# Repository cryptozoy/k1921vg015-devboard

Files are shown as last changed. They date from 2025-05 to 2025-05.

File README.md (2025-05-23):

# К1921ВГ015 DEVBOARD

Проект печатной платы для микроконтроллера К1921ВГ015 разработанный в KiCad 9.

Пожалуйста учитывайте, что фото может незначительно отличаться от платы в проекте, поскольку туда могут вноситься мелкие исправления.

Если вы хотите последнюю версию гербер файлов - рекомендуется формировать их самим, что гарантирует их актуальность.

Файлы сверловки экспортированы с настройками по умолчанию и лежат в `/gerber/`

Требования для 5$ в nextPCB были учтены и лично мной проверены.

Огромное спасибо: [@cryptozoy](https://github.com/cryptozoy) за доработку платы.

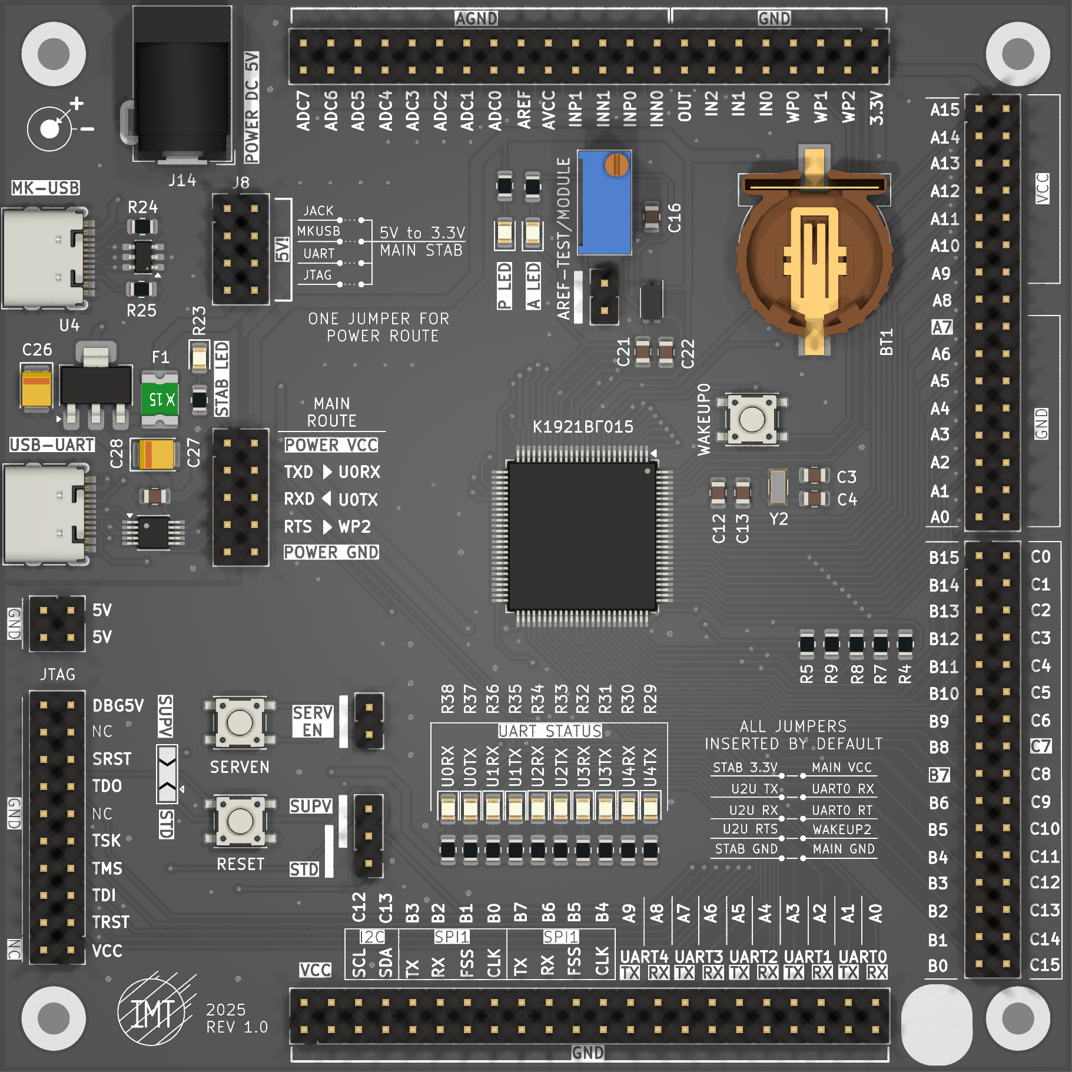
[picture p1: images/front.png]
Banner


Все пины контроллера задействованы, все функциональные пины выведены на гребёнки:

 - Порты ABC

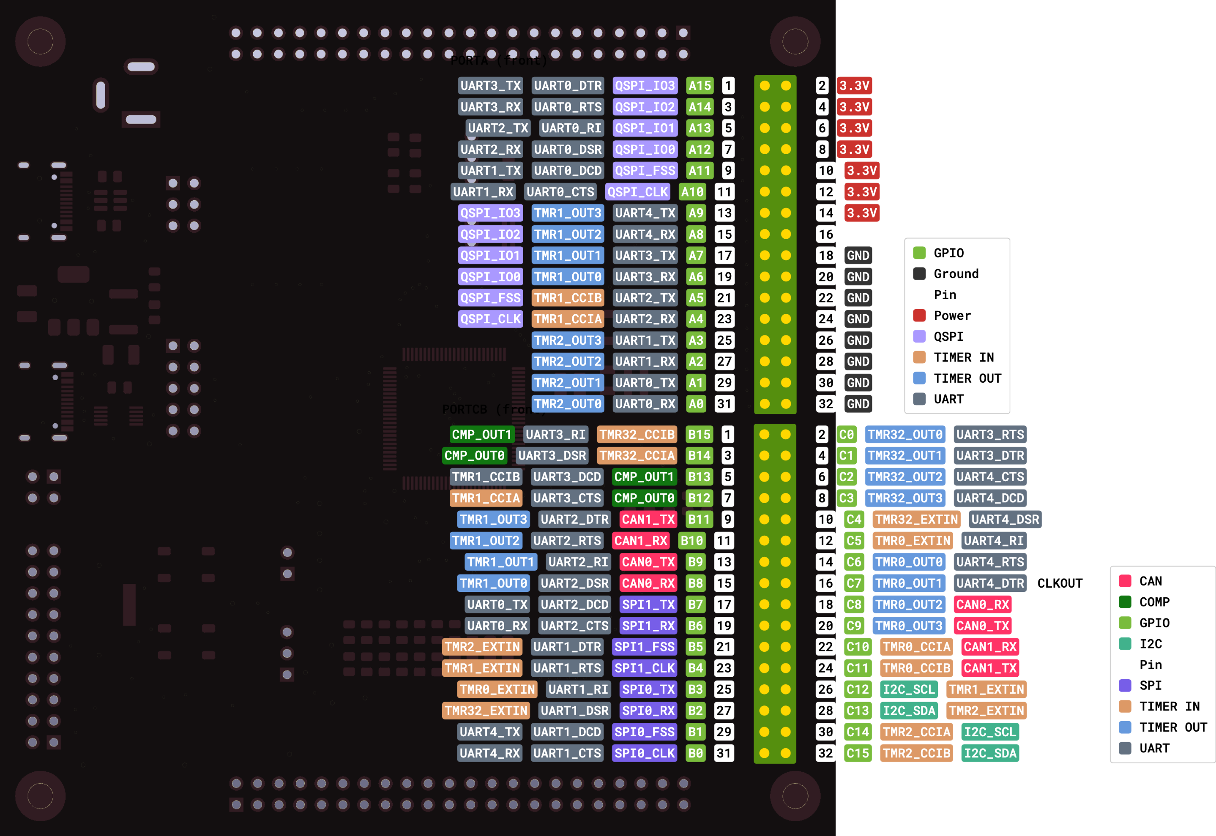
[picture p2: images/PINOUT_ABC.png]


 - Функциональные пины и коммуникация

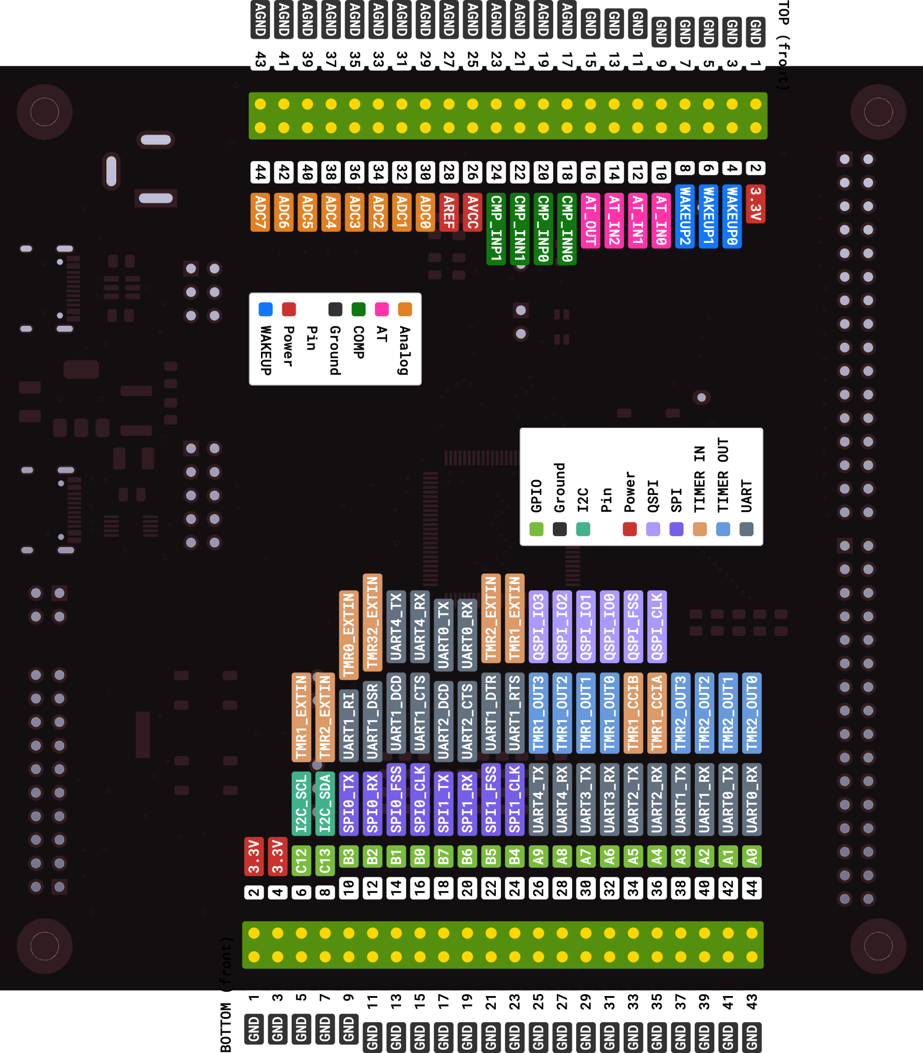
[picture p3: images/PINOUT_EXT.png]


Файлы для генерации пинаутов лежат в папке `pinouts`

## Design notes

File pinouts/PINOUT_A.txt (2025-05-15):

title: "PORTA"

# dimensions counted in pins
width: 2
height: 16

pins:
  left:
    - [ "1", "A15:gpio", "QSPI_IO3:qspi", "UART0_DTR:uart", "UART3_TX:uart"]
    - [ "3", "A14:gpio", "QSPI_IO2:qspi", "UART0_RTS:uart", "UART3_RX:uart" ]
    - [ "5", "A13:gpio", "QSPI_IO1:qspi", "UART0_RI:uart", "UART2_TX:uart" ]
    - [ "7", "A12:gpio", "QSPI_IO0:qspi", "UART0_DSR:uart", "UART2_RX:uart" ]
    - [ "9", "A11:gpio", "QSPI_FSS:qspi", "UART0_DCD:uart", "UART1_TX:uart" ]
    - [ "11", "A10:gpio", "QSPI_CLK:qspi", "UART0_CTS:uart", "UART1_RX:uart"  ]
    - [ "13", "A9:gpio", "UART4_TX:uart", "TMR1_OUT3:timo", "QSPI_IO3:qspi" ]
    - [ "15", "A8:gpio", "UART4_RX:uart", "TMR1_OUT2:timo", "QSPI_IO2:qspi" ]
    - [ "17", "A7:gpio", "UART3_TX:uart", "TMR1_OUT1:timo", "QSPI_IO1:qspi"]
    - [ "19", "A6:gpio", "UART3_RX:uart", "TMR1_OUT0:timo", "QSPI_IO0:qspi" ]
    - [ "21", "A5:gpio", "UART2_TX:uart", "TMR1_CCIB:timi", "QSPI_FSS:qspi" ]
    - [ "23", "A4:gpio", "UART2_RX:uart", "TMR1_CCIA:timi", "QSPI_CLK:qspi" ]
    - [ "25", "A3:gpio", "UART1_TX:uart", "TMR2_OUT3:timo" ]
    - [ "27", "A2:gpio", "UART1_RX:uart", "TMR2_OUT2:timo" ]
    - [ "29", "A1:gpio", "UART0_TX:uart", "TMR2_OUT1:timo" ]
    - [ "31", "A0:gpio", "UART0_RX:uart", "TMR2_OUT0:timo" ]

  right:
    - [ "2", "3.3V:power" ]
    - [ "4", "3.3V:power" ]
    - [ "6", "3.3V:power" ]
    - [ "8", "3.3V:power" ]
    - [ "10", "3.3V:power" ]
    - [ "12", "3.3V:power" ]
    - [ "14", "3.3V:power" ]
    - [ "16" ]
    - [ "18", "GND:gnd" ]
    - [ "20", "GND:gnd" ]
    - [ "22", "GND:gnd" ]
    - [ "24", "GND:gnd" ]
    - [ "26", "GND:gnd" ]
    - [ "28", "GND:gnd" ]
    - [ "30", "GND:gnd" ]
    - [ "32", "GND:gnd" ]

types:
  timo:
    bgcolor: "#6699DD"
    label: "TIMER OUT"
    fgcolor: "#FFFFFF"
  
  timi:
    bgcolor: "#DD9966"
    label: "TIMER IN"
    fgcolor: "#FFFFFF"
  
  qspi: 
    bgcolor: "#AA99FF"
    label: "QSPI"
    fgcolor: "#FFFFFF"

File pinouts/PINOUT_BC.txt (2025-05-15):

title: "PORTA"

# dimensions counted in pins
width: 2
height: 16

pins:
  left:
    - [ "1", "B15:gpio", "TMR32_CCIB:timi", "UART3_RI:uart", "CMP_OUT1:comp"]
    - [ "3", "B14:gpio", "TMR32_CCIA:timi", "UART3_DSR:uart", "CMP_OUT0:comp" ]
    - [ "5", "B13:gpio", "CMP_OUT1:comp", "UART3_DCD:uart", "TMR1_CCIB:uart" ]
    - [ "7", "B12:gpio", "CMP_OUT0:comp", "UART3_CTS:uart", "TMR1_CCIA:timi" ]
    - [ "9", "B11:gpio", "CAN1_TX:can", "UART2_DTR:uart", "TMR1_OUT3:timo" ]
    - [ "11", "B10:gpio", "CAN1_RX:can", "UART2_RTS:uart", "TMR1_OUT2:timo"  ]
    - [ "13", "B9:gpio", "CAN0_TX:can", "UART2_RI:uart", "TMR1_OUT1:timo" ]
    - [ "15", "B8:gpio", "CAN0_RX:can", "UART2_DSR:uart", "TMR1_OUT0:timo" ]
    - [ "17", "B7:gpio", "SPI1_TX:spi", "UART2_DCD:uart", "UART0_TX:uart"]
    - [ "19", "B6:gpio", "SPI1_RX:spi", "UART2_CTS:uart", "UART0_RX:uart" ]
    - [ "21", "B5:gpio", "SPI1_FSS:spi", "UART1_DTR:uart", "TMR2_EXTIN:timi" ]
    - [ "23", "B4:gpio", "SPI1_CLK:spi", "UART1_RTS:uart","TMR1_EXTIN:timi" ]
    - [ "25", "B3:gpio", "SPI0_TX:spi","UART1_RI:uart", "TMR0_EXTIN:timi" ]
    - [ "27", "B2:gpio", "SPI0_RX:spi", "UART1_DSR:uart", "TMR32_EXTIN:timi" ]
    - [ "29", "B1:gpio", "SPI0_FSS:spi", "UART1_DCD:uart", "UART4_TX:uart" ]
    - [ "31", "B0:gpio", "SPI0_CLK:spi", "UART1_CTS:uart", "UART4_RX:uart" ]

  right:
    - [ "2", "C0:gpio", "TMR32_OUT0:timo", "UART3_RTS:uart"]
    - [ "4", "C1:gpio", "TMR32_OUT1:timo", "UART3_DTR:uart" ]
    - [ "6", "C2:gpio", "TMR32_OUT2:timo", "UART4_CTS:uart" ]
    - [ "8", "C3:gpio", "TMR32_OUT3:timo", "UART4_DCD:uart" ]
    - [ "10", "C4:gpio", "TMR32_EXTIN:timi", "UART4_DSR:uart"]
    - [ "12", "C5:gpio", "TMR0_EXTIN:timi", "UART4_RI:uart"]
    - [ "14", "C6:gpio", "TMR0_OUT0:timo", "UART4_RTS:uart" ]
    - [ "16", "C7:gpio", "TMR0_OUT1:timo", "UART4_DTR:uart", "CLKOUT"  ]
    - [ "18", "C8:gpio", "TMR0_OUT2:timo", "CAN0_RX:can" ]
    - [ "20", "C9:gpio", "TMR0_OUT3:timo", "CAN0_TX:can" ]
    - [ "22", "C10:gpio", "TMR0_CCIA:timo", "CAN1_RX:can" ]
    - [ "24", "C11:gpio", "TMR0_CCIB:timo", "CAN1_TX:can" ]
    - [ "26", "C12:gpio", "I2C_SCL:i2c", "TMR1_EXTIN:timi" ]
    - [ "28", "C13:gpio", "I2C_SDA:i2c", "TMR2_EXTIN:timi" ]
    - [ "30", "C14:gpio", "TMR2_CCIA:timi", "I2C_SCL:i2c" ]
    - [ "32", "C15:gpio", "TMR2_CCIB:timi", "I2C_SDA:i2c" ]

types:
  timo:
    bgcolor: "#6699DD"
    label: "TIMER OUT"
    fgcolor: "#FFFFFF"
  
  timi:
    bgcolor: "#DD9966"
    label: "TIMER IN"
    fgcolor: "#FFFFFF"
  
  qspi: 
    bgcolor: "#AA99FF"
    label: "QSPI"
    fgcolor: "#FFFFFF"
  can: 
    bgcolor: "#FF3366"
    label: "CAN"
    fgcolor: "#FFFFFF"
  comp: 
    bgcolor: "#117711"
    label: "COMP"
    fgcolor: "#FFFFFF"

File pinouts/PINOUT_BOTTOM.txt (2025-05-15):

title: "BOTTOM"

# dimensions counted in pins
width: 2
height: 22

pins:
  left:
    - [ "1", "GND:gnd"]
    - [ "3", "GND:gnd" ]
    - [ "5", "GND:gnd" ]
    - [ "7", "GND:gnd" ]
    - [ "9", "GND:gnd" ]
    - [ "11", "GND:gnd" ]
    - [ "13", "GND:gnd" ]
    - [ "15", "GND:gnd" ]
    - [ "17", "GND:gnd"]
    - [ "19", "GND:gnd" ]
    - [ "21", "GND:gnd" ]
    - [ "23", "GND:gnd" ]
    - [ "25", "GND:gnd" ]
    - [ "27", "GND:gnd" ]
    - [ "29", "GND:gnd" ]
    - [ "31", "GND:gnd" ]
    - [ "33", "GND:gnd" ]
    - [ "35", "GND:gnd" ]
    - [ "37", "GND:gnd" ]
    - [ "39", "GND:gnd" ]
    - [ "41", "GND:gnd" ]
    - [ "43", "GND:gnd" ]
    
  right:
    - [ "2", "3.3V:power"]
    - [ "4", "3.3V:power"]
    - [ "6", "C12:gpio", "I2C_SCL:i2c", "TMR1_EXTIN:timi"]
    - [ "8", "C13:gpio", "I2C_SDA:i2c", "TMR2_EXTIN:timi" ]
    - [ "10", "B3:gpio", "SPI0_TX:spi","UART1_RI:uart", "TMR0_EXTIN:timi"]
    - [ "12", "B2:gpio", "SPI0_RX:spi", "UART1_DSR:uart", "TMR32_EXTIN:timi"]
    - [ "14", "B1:gpio", "SPI0_FSS:spi", "UART1_DCD:uart", "UART4_TX:uart" ]
    - [ "16", "B0:gpio", "SPI0_CLK:spi", "UART1_CTS:uart", "UART4_RX:uart"  ]
    - [ "18", "B7:gpio", "SPI1_TX:spi", "UART2_DCD:uart", "UART0_TX:uart" ]
    - [ "20", "B6:gpio", "SPI1_RX:spi", "UART2_CTS:uart", "UART0_RX:uart" ]
    - [ "22", "B5:gpio", "SPI1_FSS:spi", "UART1_DTR:uart", "TMR2_EXTIN:timi" ]
    - [ "24", "B4:gpio", "SPI1_CLK:spi", "UART1_RTS:uart","TMR1_EXTIN:timi" ]
    - [ "26", "A9:gpio", "UART4_TX:uart", "TMR1_OUT3:timo", "QSPI_IO3:qspi" ]
    - [ "28", "A8:gpio", "UART4_RX:uart", "TMR1_OUT2:timo", "QSPI_IO2:qspi"  ]
    - [ "30", "A7:gpio", "UART3_TX:uart", "TMR1_OUT1:timo", "QSPI_IO1:qspi" ]
    - [ "32", "A6:gpio", "UART3_RX:uart", "TMR1_OUT0:timo", "QSPI_IO0:qspi" ]
    - [ "34", "A5:gpio", "UART2_TX:uart", "TMR1_CCIB:timi", "QSPI_FSS:qspi" ]
    - [ "36", "A4:gpio", "UART2_RX:uart", "TMR1_CCIA:timi", "QSPI_CLK:qspi" ]
    - [ "38", "A3:gpio", "UART1_TX:uart", "TMR2_OUT3:timo" ]
    - [ "40", "A2:gpio", "UART1_RX:uart", "TMR2_OUT2:timo" ]
    - [ "42", "A1:gpio", "UART0_TX:uart", "TMR2_OUT1:timo" ]
    - [ "44", "A0:gpio", "UART0_RX:uart", "TMR2_OUT0:timo" ]
    
types:
  timo:
    bgcolor: "#6699DD"
    label: "TIMER OUT"
    fgcolor: "#FFFFFF"
  
  timi:
    bgcolor: "#DD9966"
    label: "TIMER IN"
    fgcolor: "#FFFFFF"
  
  qspi: 
    bgcolor: "#AA99FF"
    label: "QSPI"
    fgcolor: "#FFFFFF"
  can: 
    bgcolor: "#FF3366"
    label: "CAN"
    fgcolor: "#FFFFFF"
  comp: 
    bgcolor: "#117711"
    label: "COMP"
    fgcolor: "#FFFFFF"

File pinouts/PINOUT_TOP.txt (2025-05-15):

title: "TOP"

# dimensions counted in pins
width: 2
height: 22

pins:
  left:
    - [ "1", "GND:gnd"]
    - [ "3", "GND:gnd" ]
    - [ "5", "GND:gnd" ]
    - [ "7", "GND:gnd" ]
    - [ "9", "GND:gnd" ]
    - [ "11", "GND:gnd" ]
    - [ "13", "GND:gnd" ]
    - [ "15", "GND:gnd" ]
    - [ "17", "AGND:gnd"]
    - [ "19", "AGND:gnd" ]
    - [ "21", "AGND:gnd" ]
    - [ "23", "AGND:gnd" ]
    - [ "25", "AGND:gnd" ]
    - [ "27", "AGND:gnd" ]
    - [ "29", "AGND:gnd" ]
    - [ "31", "AGND:gnd" ]
    - [ "33", "AGND:gnd" ]
    - [ "35", "AGND:gnd" ]
    - [ "37", "AGND:gnd" ]
    - [ "39", "AGND:gnd" ]
    - [ "41", "AGND:gnd" ]
    - [ "43", "AGND:gnd" ]
    
  right:
    - [ "2", "3.3V:power"]
    - [ "4", "WAKEUP0:wkp"]
    - [ "6", "WAKEUP1:wkp"]
    - [ "8", "WAKEUP2:wkp" ]
    - [ "10", "AT_IN0:at"]
    - [ "12", "AT_IN1:at"]
    - [ "14", "AT_IN2:at"]
    - [ "16", "AT_OUT:at"]
    - [ "18", "CMP_INN0:comp"]
    - [ "20", "CMP_INP0:comp"]
    - [ "22", "CMP_INN1:comp"]
    - [ "24", "CMP_INP1:comp"]
    - [ "26", "AVCC:power" ]
    - [ "28", "AREF:power"  ]
    - [ "30", "ADC0:analog" ]
    - [ "32", "ADC1:analog" ]
    - [ "34", "ADC2:analog" ]
    - [ "36", "ADC3:analog" ]
    - [ "38", "ADC4:analog" ]
    - [ "40", "ADC5:analog" ]
    - [ "42", "ADC6:analog" ]
    - [ "44", "ADC7:analog" ]
    
types:
  timo:
    bgcolor: "#6699DD"
    label: "TIMER OUT"
    fgcolor: "#FFFFFF"
  
  timi:
    bgcolor: "#DD9966"
    label: "TIMER IN"
    fgcolor: "#FFFFFF"
  
  qspi: 
    bgcolor: "#AA99FF"
    label: "QSPI"
    fgcolor: "#FFFFFF"
  can: 
    bgcolor: "#FF3366"
    label: "CAN"
    fgcolor: "#FFFFFF"
  comp: 
    bgcolor: "#117711"
    label: "COMP"
    fgcolor: "#FFFFFF"
  wkp: 
    bgcolor: "#1177FF"
    label: "WAKEUP"
    fgcolor: "#FFFFFF"
  at: 
    bgcolor: "#ff33AA"
    label: "AT"
    fgcolor: "#FFFFFF"

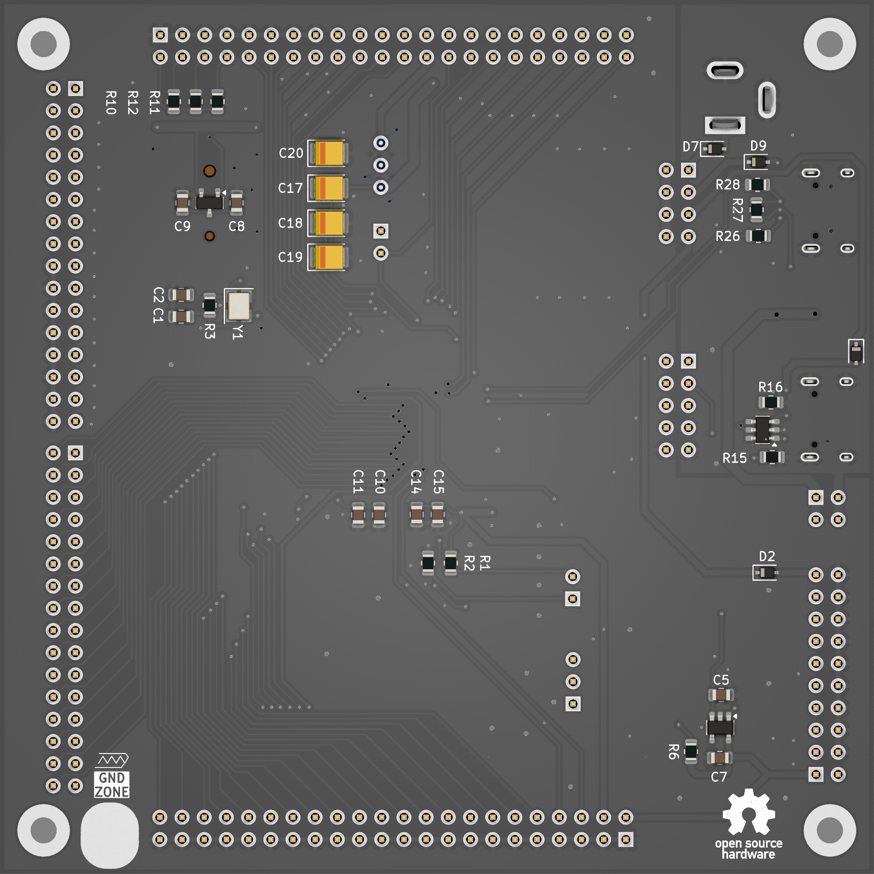
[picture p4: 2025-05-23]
images/back.png

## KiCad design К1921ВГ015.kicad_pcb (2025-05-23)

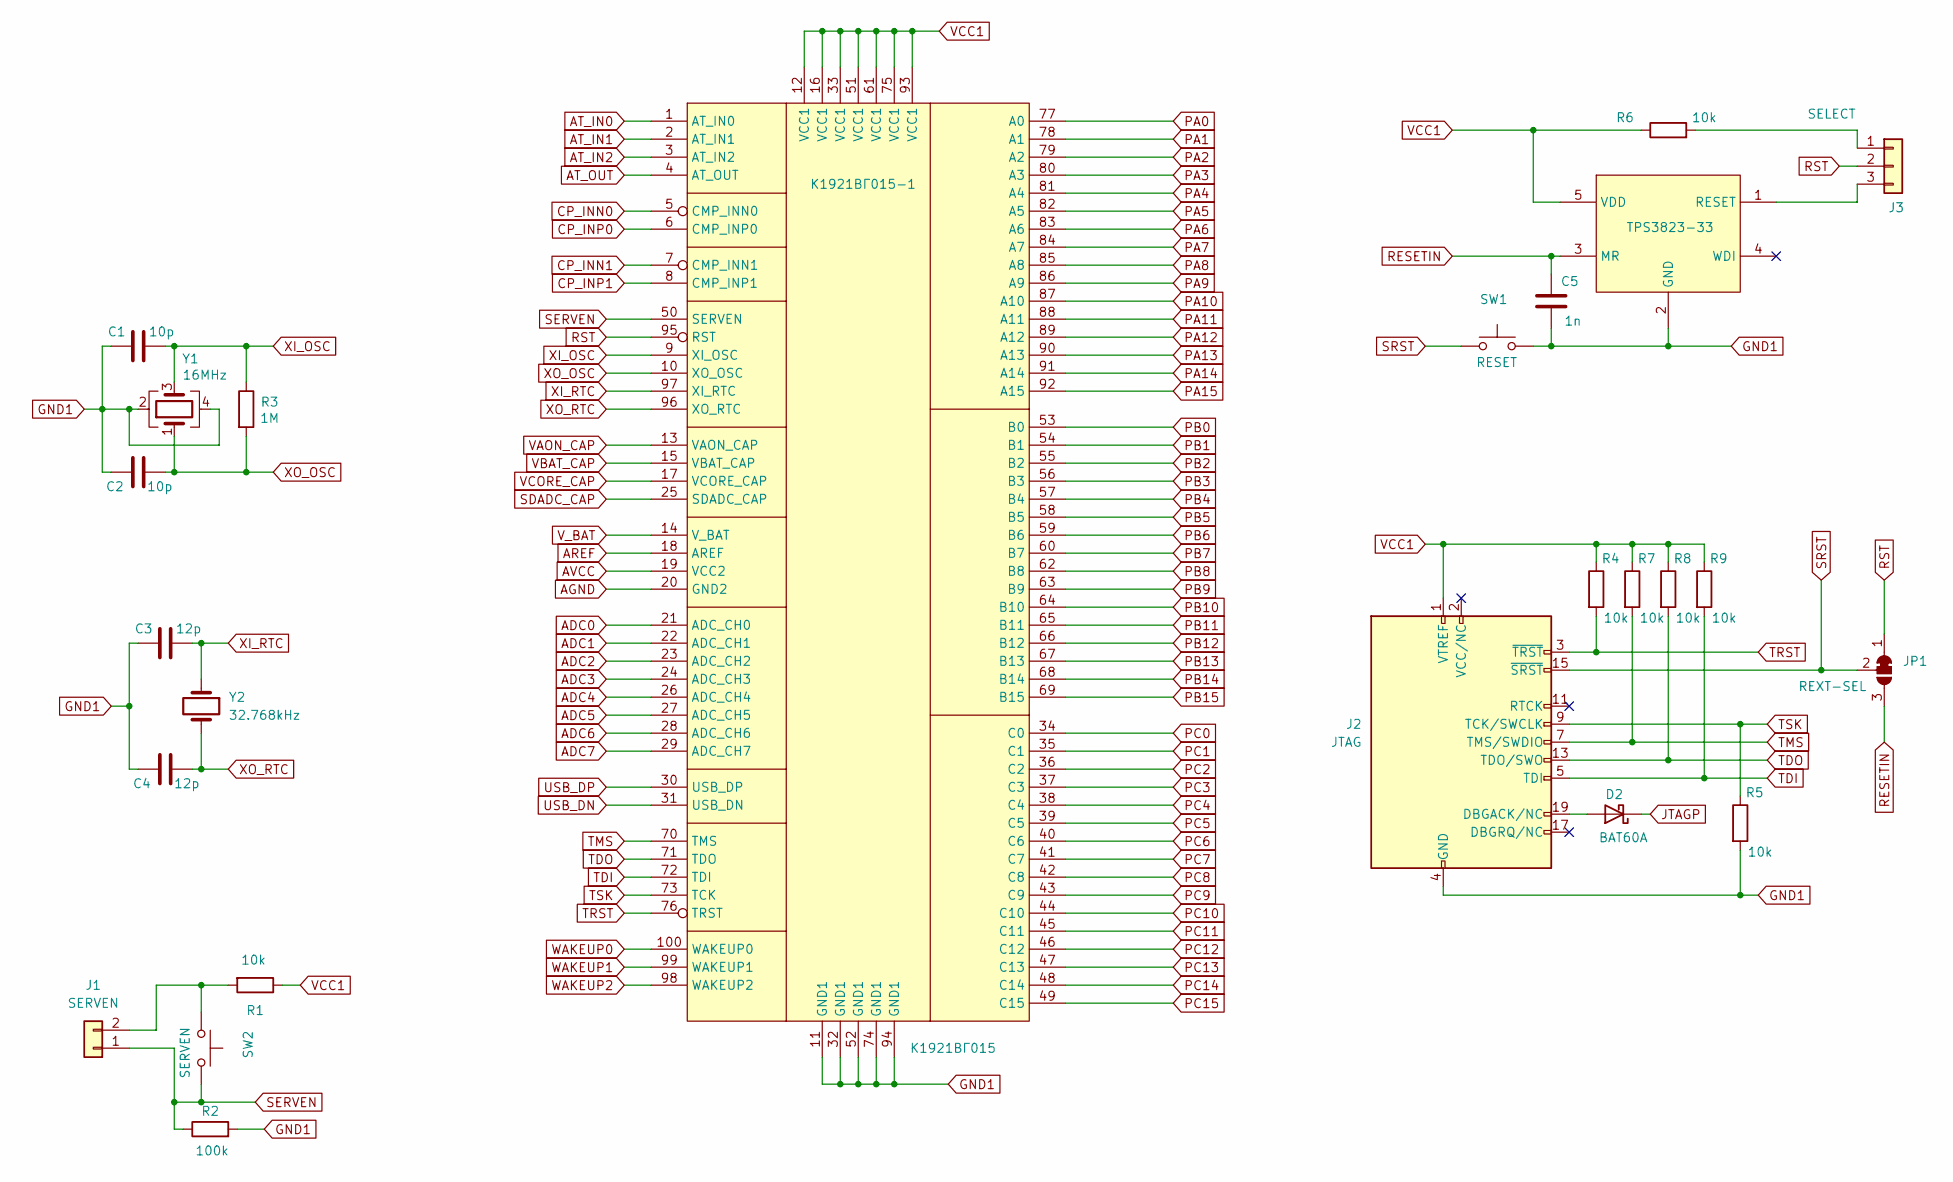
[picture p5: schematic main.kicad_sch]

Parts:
C1, C2: 10p; C_0805_2012Metric
C3, C4: 12p; C_0805_2012Metric
C5: 1n; C_0805_2012Metric
D2: BAT60A; D_SOD-323
J1: SERVEN; PinHeader_1x02_P2.54mm_Vertical
J2: JTAG; PinHeader_2x10_P2.54mm_Vertical
J3: SELECT; PinHeader_1x03_P2.54mm_Vertical
JP1: REXT-SEL; SolderJumper-3_P2.0mm_Open_TrianglePad1.0x1.5mm
R1, R4, R5, R6, R7, R8, R9: 10k; R_0805_2012Metric
R2: 100k; R_0805_2012Metric
R3: 1M; R_0805_2012Metric
SW1: RESET; SW_SPST_PTS647_Sx38
SW2: SERVEN; SW_SPST_PTS647_Sx38
TPS3823-1: TPS3823-33; SOT-23-5
Y1: 16MHz; Crystal_SMD_3225-4Pin_3.2x2.5mm
Y2: 32.768kHz; Crystal_SMD_3215-2Pin_3.2x1.5mm
К1921ВГ015-1: К1921ВГ015; LQFP-100_14x14mm_P0.5mm

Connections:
ADC0: К1921ВГ015-1.21 (ADC_CH0); also elsewhere on the board
ADC1: К1921ВГ015-1.22 (ADC_CH1); also elsewhere on the board
ADC2: К1921ВГ015-1.23 (ADC_CH2); also elsewhere on the board
ADC3: К1921ВГ015-1.24 (ADC_CH3); also elsewhere on the board
ADC4: К1921ВГ015-1.26 (ADC_CH4); also elsewhere on the board
ADC5: К1921ВГ015-1.27 (ADC_CH5); also elsewhere on the board
ADC6: К1921ВГ015-1.28 (ADC_CH6); also elsewhere on the board
ADC7: К1921ВГ015-1.29 (ADC_CH7); also elsewhere on the board
AGND: К1921ВГ015-1.20 (GND2); also elsewhere on the board
AREF: К1921ВГ015-1.18 (AREF); also elsewhere on the board
AT_IN0: К1921ВГ015-1.1 (AT_IN0); also elsewhere on the board
AT_IN1: К1921ВГ015-1.2 (AT_IN1); also elsewhere on the board
AT_IN2: К1921ВГ015-1.3 (AT_IN2); also elsewhere on the board
AT_OUT: К1921ВГ015-1.4 (AT_OUT); also elsewhere on the board
AVCC: К1921ВГ015-1.19 (VCC2); also elsewhere on the board
CAN0_RX: К1921ВГ015-1.42 (C8); also elsewhere on the board
CAN0_TX: К1921ВГ015-1.43 (C9); also elsewhere on the board
CAN1_RX: К1921ВГ015-1.44 (C10); also elsewhere on the board
CAN1_TX: К1921ВГ015-1.45 (C11); also elsewhere on the board
CP_INN0: К1921ВГ015-1.5 (CMP_INN0); also elsewhere on the board
CP_INN1: К1921ВГ015-1.7 (CMP_INN1); also elsewhere on the board
CP_INP0: К1921ВГ015-1.6 (CMP_INP0); also elsewhere on the board
CP_INP1: К1921ВГ015-1.8 (CMP_INP1); also elsewhere on the board
GND1: C1.2, C2.2, C3.2, C4.2, C5.2, J2.4 (GND), J2.6 (GND), J2.8 (GND), J2.10 (GND), J2.12 (GND), J2.14 (GND), J2.16 (GND), J2.18 (GND), J2.20 (GND), R2.2, R5.2, SW1.2, TPS3823-1.2 (GND), Y1.2, Y1.4, К1921ВГ015-1.11 (GND1), К1921ВГ015-1.32 (GND1), К1921ВГ015-1.52 (GND1), К1921ВГ015-1.74 (GND1), К1921ВГ015-1.94 (GND1); also elsewhere on the board
I2C_SCL: К1921ВГ015-1.46 (C12); also elsewhere on the board
I2C_SDA: К1921ВГ015-1.47 (C13); also elsewhere on the board
unnamed: D2.2 (A), J2.19 (DBGACK/NC)
unnamed: J1.2, R1.2, SW2.1
unnamed: J3.1, R6.2
unnamed: J3.3, TPS3823-1.1 (RESET)
PA0: К1921ВГ015-1.77 (A0); also elsewhere on the board
PA1: К1921ВГ015-1.78 (A1); also elsewhere on the board
PA2: К1921ВГ015-1.79 (A2); also elsewhere on the board
PA3: К1921ВГ015-1.80 (A3); also elsewhere on the board
PA4: К1921ВГ015-1.81 (A4); also elsewhere on the board
PA5: К1921ВГ015-1.82 (A5); also elsewhere on the board
PA6: К1921ВГ015-1.83 (A6); also elsewhere on the board
PA7: К1921ВГ015-1.84 (A7); also elsewhere on the board
PA8: К1921ВГ015-1.85 (A8); also elsewhere on the board
PA9: К1921ВГ015-1.86 (A9); also elsewhere on the board
PA10: К1921ВГ015-1.87 (A10); also elsewhere on the board
PA11: К1921ВГ015-1.88 (A11); also elsewhere on the board
PA12: К1921ВГ015-1.89 (A12); also elsewhere on the board
PA13: К1921ВГ015-1.90 (A13); also elsewhere on the board
PA14: К1921ВГ015-1.91 (A14); also elsewhere on the board
PA15: К1921ВГ015-1.92 (A15); also elsewhere on the board
PB0: К1921ВГ015-1.53 (B0); also elsewhere on the board
PB1: К1921ВГ015-1.54 (B1); also elsewhere on the board
PB2: К1921ВГ015-1.55 (B2); also elsewhere on the board
PB3: К1921ВГ015-1.56 (B3); also elsewhere on the board
PB4: К1921ВГ015-1.57 (B4); also elsewhere on the board
PB5: К1921ВГ015-1.58 (B5); also elsewhere on the board
PB6: К1921ВГ015-1.59 (B6); also elsewhere on the board
PB7: К1921ВГ015-1.60 (B7); also elsewhere on the board
PB8: К1921ВГ015-1.62 (B8); also elsewhere on the board
PB9: К1921ВГ015-1.63 (B9); also elsewhere on the board
PB10: К1921ВГ015-1.64 (B10); also elsewhere on the board
PB11: К1921ВГ015-1.65 (B11); also elsewhere on the board
PB12: К1921ВГ015-1.66 (B12); also elsewhere on the board
PB13: К1921ВГ015-1.67 (B13); also elsewhere on the board
PB14: К1921ВГ015-1.68 (B14); also elsewhere on the board
PB15: К1921ВГ015-1.69 (B15); also elsewhere on the board
PC0: К1921ВГ015-1.34 (C0); also elsewhere on the board
PC1: К1921ВГ015-1.35 (C1); also elsewhere on the board
PC2: К1921ВГ015-1.36 (C2); also elsewhere on the board
PC3: К1921ВГ015-1.37 (C3); also elsewhere on the board
PC4: К1921ВГ015-1.38 (C4); also elsewhere on the board
PC5: К1921ВГ015-1.39 (C5); also elsewhere on the board
PC6: К1921ВГ015-1.40 (C6); also elsewhere on the board
PC7: К1921ВГ015-1.41 (C7); also elsewhere on the board
PC14: К1921ВГ015-1.48 (C14); also elsewhere on the board
PC15: К1921ВГ015-1.49 (C15); also elsewhere on the board
PJTAG: D2.1 (K); also elsewhere on the board
RESETIN: C5.1, JP1.3 (B), TPS3823-1.3 (MR)
RST: J3.2, JP1.1 (A), К1921ВГ015-1.95 (RST)
SDADC_CAP: К1921ВГ015-1.25 (SDADC_CAP); also elsewhere on the board
SERVEN: J1.1, R2.1, SW2.2, К1921ВГ015-1.50 (SERVEN)
SRST: J2.15 (~SRST), JP1.2 (C), SW1.1
TDI: J2.5 (TDI), R9.2, К1921ВГ015-1.72 (TDI)
TDO: J2.13 (TDO/SWO), R8.2, К1921ВГ015-1.71 (TDO)
TMS: J2.7 (TMS/SWDIO), R7.2, К1921ВГ015-1.70 (TMS)
TRST: J2.3 (~TRST), R4.2, К1921ВГ015-1.76 (TRST)
TSK: J2.9 (TCK/SWCLK), R5.1, К1921ВГ015-1.73 (TCK)
USB_DN: К1921ВГ015-1.31 (USB_DN); also elsewhere on the board
USB_DP: К1921ВГ015-1.30 (USB_DP); also elsewhere on the board
VAON_CAP: К1921ВГ015-1.13 (VAON_CAP); also elsewhere on the board
VBAT_CAP: К1921ВГ015-1.15 (VBAT_CAP); also elsewhere on the board
VCC1: J2.1 (VTREF), R1.1, R4.1, R6.1, R7.1, R8.1, R9.1, TPS3823-1.5 (VDD), К1921ВГ015-1.12 (VCC1), К1921ВГ015-1.16 (VCC1), К1921ВГ015-1.33 (VCC1), К1921ВГ015-1.51 (VCC1), К1921ВГ015-1.61 (VCC1), К1921ВГ015-1.75 (VCC1), К1921ВГ015-1.93 (VCC1); also elsewhere on the board
VCORE_CAP: К1921ВГ015-1.17 (VCORE_CAP); also elsewhere on the board
V_BAT: К1921ВГ015-1.14 (V_BAT); also elsewhere on the board
WAKEUP0: К1921ВГ015-1.100 (WAKEUP0); also elsewhere on the board
WAKEUP1: К1921ВГ015-1.99 (WAKEUP1); also elsewhere on the board
WAKEUP2: К1921ВГ015-1.98 (WAKEUP2); also elsewhere on the board
XI_OSC: C1.1, R3.1, Y1.3, К1921ВГ015-1.9 (XI_OSC)
XI_RTC: C3.1, Y2.1, К1921ВГ015-1.97 (XI_RTC)
XO_OSC: C2.1, R3.2, Y1.1, К1921ВГ015-1.10 (XO_OSC)
XO_RTC: C4.1, Y2.2, К1921ВГ015-1.96 (XO_RTC)

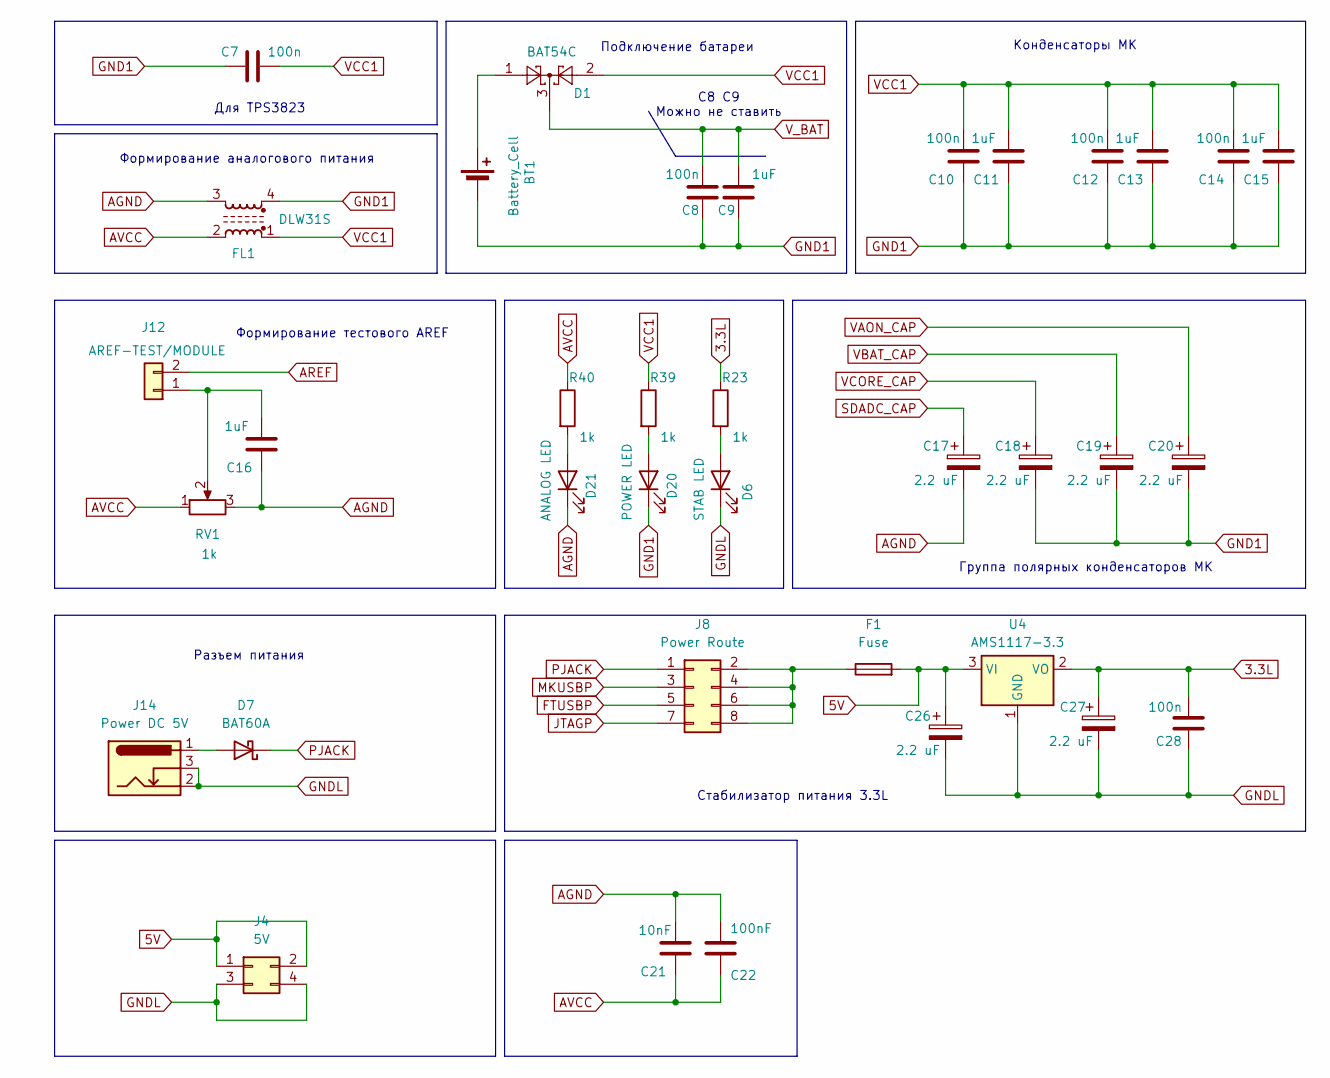
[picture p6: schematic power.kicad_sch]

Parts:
BT1: Battery_Cell; Battery_Panasonic_CR2032-HFN_Horizontal_CircularHoles
C7, C8, C10, C12, C14, C28: 100n; C_0805_2012Metric
C9, C11, C13, C15, C16: 1uF; C_0805_2012Metric
C17, C18, C19, C20, C26, C27: 2.2 uF; CP_EIA-3528-21_Kemet-B
C21: 10nF; C_0805_2012Metric
C22: 100nF; C_0805_2012Metric
D1: BAT54C; SOT-23
D6: STAB LED; LED_0805_2012Metric
D7: BAT60A; D_SOD-323
D20: POWER LED; LED_0805_2012Metric
D21: ANALOG LED; LED_0805_2012Metric
F1: Fuse; Fuse_1812_4532Metric
FL1: DLW31S; L_CommonMode_Wurth_WE-CNSW-1206
J4: 5V; PinHeader_2x02_P2.54mm_Vertical
J8: Power Route; PinHeader_2x04_P2.54mm_Vertical
J12: AREF-TEST/MODULE; PinHeader_1x02_P2.54mm_Vertical
J14: Power DC 5V; BarrelJack_GCT_DCJ200-10-A_Horizontal
R23, R39, R40: 1k; R_0805_2012Metric
RV1: 1k; Potentiometer_Bourns_3296W_Vertical
U4: AMS1117-3.3; SOT-223-3_TabPin2

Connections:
3.3L: C27.1, C28.1, R23.1, U4.2 (VO); also elsewhere on the board
5V: C26.1, F1.2, J4.1, J4.2, U4.3 (VI)
AGND: C16.2, C17.2, C21.1, C22.1, D21.1 (K), FL1.3, RV1.3; also elsewhere on the board
AREF: J12.2; also elsewhere on the board
AVCC: C21.2, C22.2, FL1.2, R40.1, RV1.1; also elsewhere on the board
FTUSBP: J8.5; also elsewhere on the board
GND1: BT1.2 (-), C7.2, C8.2, C9.2, C10.2, C11.2, C12.2, C13.2, C14.2, C15.2, C18.2, C19.2, C20.2, D20.1 (K), FL1.4; also elsewhere on the board
GNDL: C26.2, C27.2, C28.2, D6.1 (K), J4.3, J4.4, J14.2, J14.3, U4.1 (GND); also elsewhere on the board
MKUSBP: J8.3; also elsewhere on the board
unnamed: BT1.1 (+), D1.1
unnamed: D6.2 (A), R23.2
unnamed: D7.2 (A), J14.1
unnamed: D20.2 (A), R39.2
unnamed: D21.2 (A), R40.2
unnamed: F1.1, J8.2, J8.4, J8.6, J8.8
unnamed: C16.1, J12.1, RV1.2
PJACK: D7.1 (K), J8.1
PJTAG: J8.7; also elsewhere on the board
SDADC_CAP: C17.1; also elsewhere on the board
VAON_CAP: C20.1; also elsewhere on the board
VBAT_CAP: C19.1; also elsewhere on the board
VCC1: C7.1, C10.1, C11.1, C12.1, C13.1, C14.1, C15.1, D1.2, FL1.1, R39.1; also elsewhere on the board
VCORE_CAP: C18.1; also elsewhere on the board
V_BAT: C8.1, C9.1, D1.3; also elsewhere on the board

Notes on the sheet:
Группа полярных конденсаторов МК
Формирование аналогового питания
Формирование тестового AREF
Подключение батареи
Конденсаторы МК
Для TPS3823
Разъем питания
С8 C9 Можно не ставить
Стабилизатор питания 3.3L

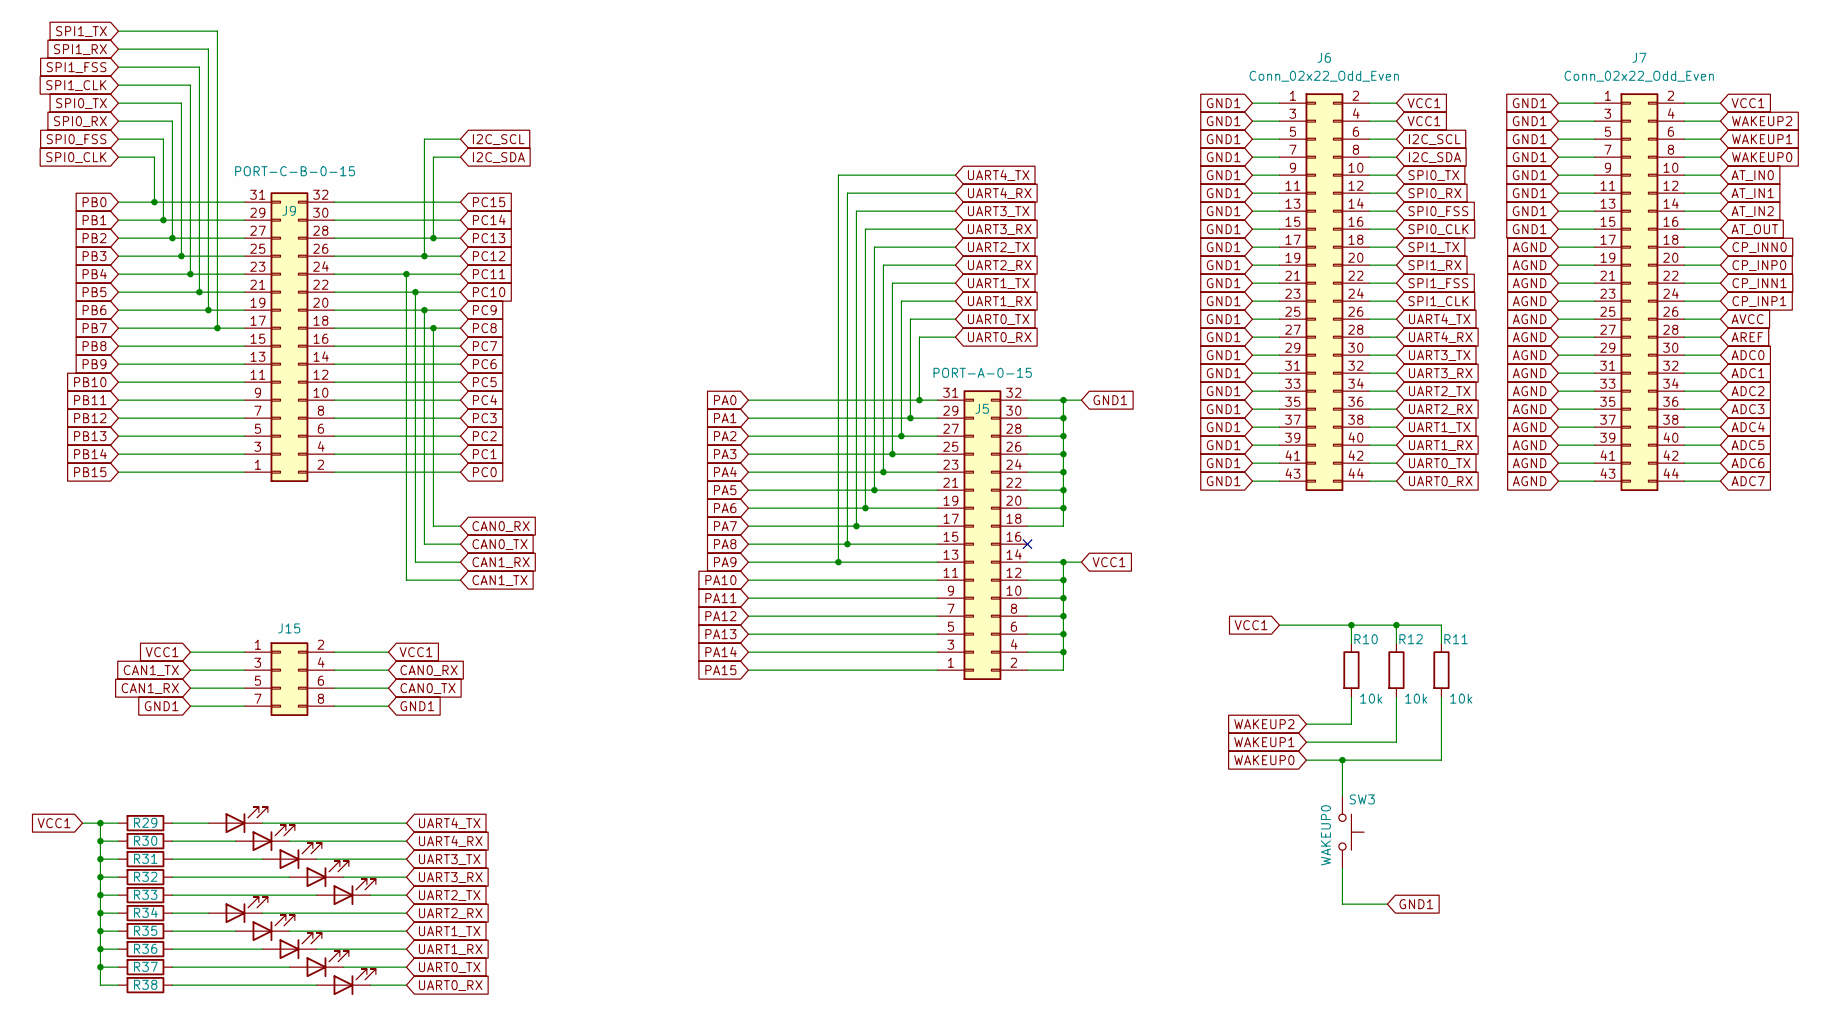
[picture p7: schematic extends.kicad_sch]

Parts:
D10: U4TX; LED_0805_2012Metric
D11: U4RX; LED_0805_2012Metric
D12: U3TX; LED_0805_2012Metric
D13: U3RX; LED_0805_2012Metric
D14: U2TX; LED_0805_2012Metric
D15: U1TX; LED_0805_2012Metric
D16: U1RX; LED_0805_2012Metric
D17: U0TX; LED_0805_2012Metric
D18: U0RX; LED_0805_2012Metric
D19: U2RX; LED_0805_2012Metric
J5: PORT-A-0-15; PinHeader_2x16_P2.54mm_Vertical
J6, J7: Conn_02x22_Odd_Even; PinHeader_2x22_P2.54mm_Vertical
J9: PORT-C-B-0-15; PinHeader_2x16_P2.54mm_Vertical
J15: Conn_02x04_Odd_Even; PinHeader_2x04_P2.54mm_Vertical
R10, R11, R12: 10k; R_0805_2012Metric
R29, R30, R31, R32, R33, R34, R35, R36, R37, R38: 1k; R_0805_2012Metric
SW3: WAKEUP0; SW_SPST_PTS647_Sx38

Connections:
ADC0: J7.30; also elsewhere on the board
ADC1: J7.32; also elsewhere on the board
ADC2: J7.34; also elsewhere on the board
ADC3: J7.36; also elsewhere on the board
ADC4: J7.38; also elsewhere on the board
ADC5: J7.40; also elsewhere on the board
ADC6: J7.42; also elsewhere on the board
ADC7: J7.44; also elsewhere on the board
AGND: J7.17, J7.19, J7.21, J7.23, J7.25, J7.27, J7.29, J7.31, J7.33, J7.35, J7.37, J7.39, J7.41, J7.43; also elsewhere on the board
AREF: J7.28; also elsewhere on the board
AT_IN0: J7.10; also elsewhere on the board
AT_IN1: J7.12; also elsewhere on the board
AT_IN2: J7.14; also elsewhere on the board
AT_OUT: J7.16; also elsewhere on the board
AVCC: J7.26; also elsewhere on the board
CAN0_RX: J9.18, J15.4; also elsewhere on the board
CAN0_TX: J9.20, J15.6; also elsewhere on the board
CAN1_RX: J9.22, J15.5; also elsewhere on the board
CAN1_TX: J9.24, J15.3; also elsewhere on the board
CP_INN0: J7.18; also elsewhere on the board
CP_INN1: J7.22; also elsewhere on the board
CP_INP0: J7.20; also elsewhere on the board
CP_INP1: J7.24; also elsewhere on the board
GND1: J5.18, J5.20, J5.22, J5.24, J5.26, J5.28, J5.30, J5.32, J6.1, J6.3, J6.5, J6.7, J6.9, J6.11, J6.13, J6.15, J6.17, J6.19, J6.21, J6.23, J6.25, J6.27, J6.29, J6.31, J6.33, J6.35, J6.37, J6.39, J6.41, J6.43, J7.1, J7.3, J7.5, J7.7, J7.9, J7.11, J7.13, J7.15, J15.7, J15.8, SW3.2; also elsewhere on the board
I2C_SCL: J6.6, J9.26; also elsewhere on the board
I2C_SDA: J6.8, J9.28; also elsewhere on the board
unnamed: D10.2 (A), R29.1
unnamed: D11.2 (A), R30.1
unnamed: D12.2 (A), R31.1
unnamed: D13.2 (A), R32.1
unnamed: D14.2 (A), R33.1
unnamed: D15.2 (A), R35.1
unnamed: D16.2 (A), R36.1
unnamed: D17.2 (A), R37.1
unnamed: D18.2 (A), R38.1
unnamed: D19.2 (A), R34.1
PA0: D18.1 (K), J5.31, J6.44; also elsewhere on the board
PA1: D17.1 (K), J5.29, J6.42; also elsewhere on the board
PA2: D16.1 (K), J5.27, J6.40; also elsewhere on the board
PA3: D15.1 (K), J5.25, J6.38; also elsewhere on the board
PA4: D19.1 (K), J5.23, J6.36; also elsewhere on the board
PA5: D14.1 (K), J5.21, J6.34; also elsewhere on the board
PA6: D13.1 (K), J5.19, J6.32; also elsewhere on the board
PA7: D12.1 (K), J5.17, J6.30; also elsewhere on the board
PA8: D11.1 (K), J5.15, J6.28; also elsewhere on the board
PA9: D10.1 (K), J5.13, J6.26; also elsewhere on the board
PA10: J5.11; also elsewhere on the board
PA11: J5.9; also elsewhere on the board
PA12: J5.7; also elsewhere on the board
PA13: J5.5; also elsewhere on the board
PA14: J5.3; also elsewhere on the board
PA15: J5.1; also elsewhere on the board
PB0: J6.16, J9.31; also elsewhere on the board
PB1: J6.14, J9.29; also elsewhere on the board
PB2: J6.12, J9.27; also elsewhere on the board
PB3: J6.10, J9.25; also elsewhere on the board
PB4: J6.24, J9.23; also elsewhere on the board
PB5: J6.22, J9.21; also elsewhere on the board
PB6: J6.20, J9.19; also elsewhere on the board
PB7: J6.18, J9.17; also elsewhere on the board
PB8: J9.15; also elsewhere on the board
PB9: J9.13; also elsewhere on the board
PB10: J9.11; also elsewhere on the board
PB11: J9.9; also elsewhere on the board
PB12: J9.7; also elsewhere on the board
PB13: J9.5; also elsewhere on the board
PB14: J9.3; also elsewhere on the board
PB15: J9.1; also elsewhere on the board
PC0: J9.2; also elsewhere on the board
PC1: J9.4; also elsewhere on the board
PC2: J9.6; also elsewhere on the board
PC3: J9.8; also elsewhere on the board
PC4: J9.10; also elsewhere on the board
PC5: J9.12; also elsewhere on the board
PC6: J9.14; also elsewhere on the board
PC7: J9.16; also elsewhere on the board
PC14: J9.30; also elsewhere on the board
PC15: J9.32; also elsewhere on the board
VCC1: J5.2, J5.4, J5.6, J5.8, J5.10, J5.12, J5.14, J6.2, J6.4, J7.2, J15.1, J15.2, R10.1, R11.1, R12.1, R29.2, R30.2, R31.2, R32.2, R33.2, R34.2, R35.2, R36.2, R37.2, R38.2; also elsewhere on the board
WAKEUP0: J7.8, R11.2, SW3.1; also elsewhere on the board
WAKEUP1: J7.6, R12.2; also elsewhere on the board
WAKEUP2: J7.4, R10.2; also elsewhere on the board

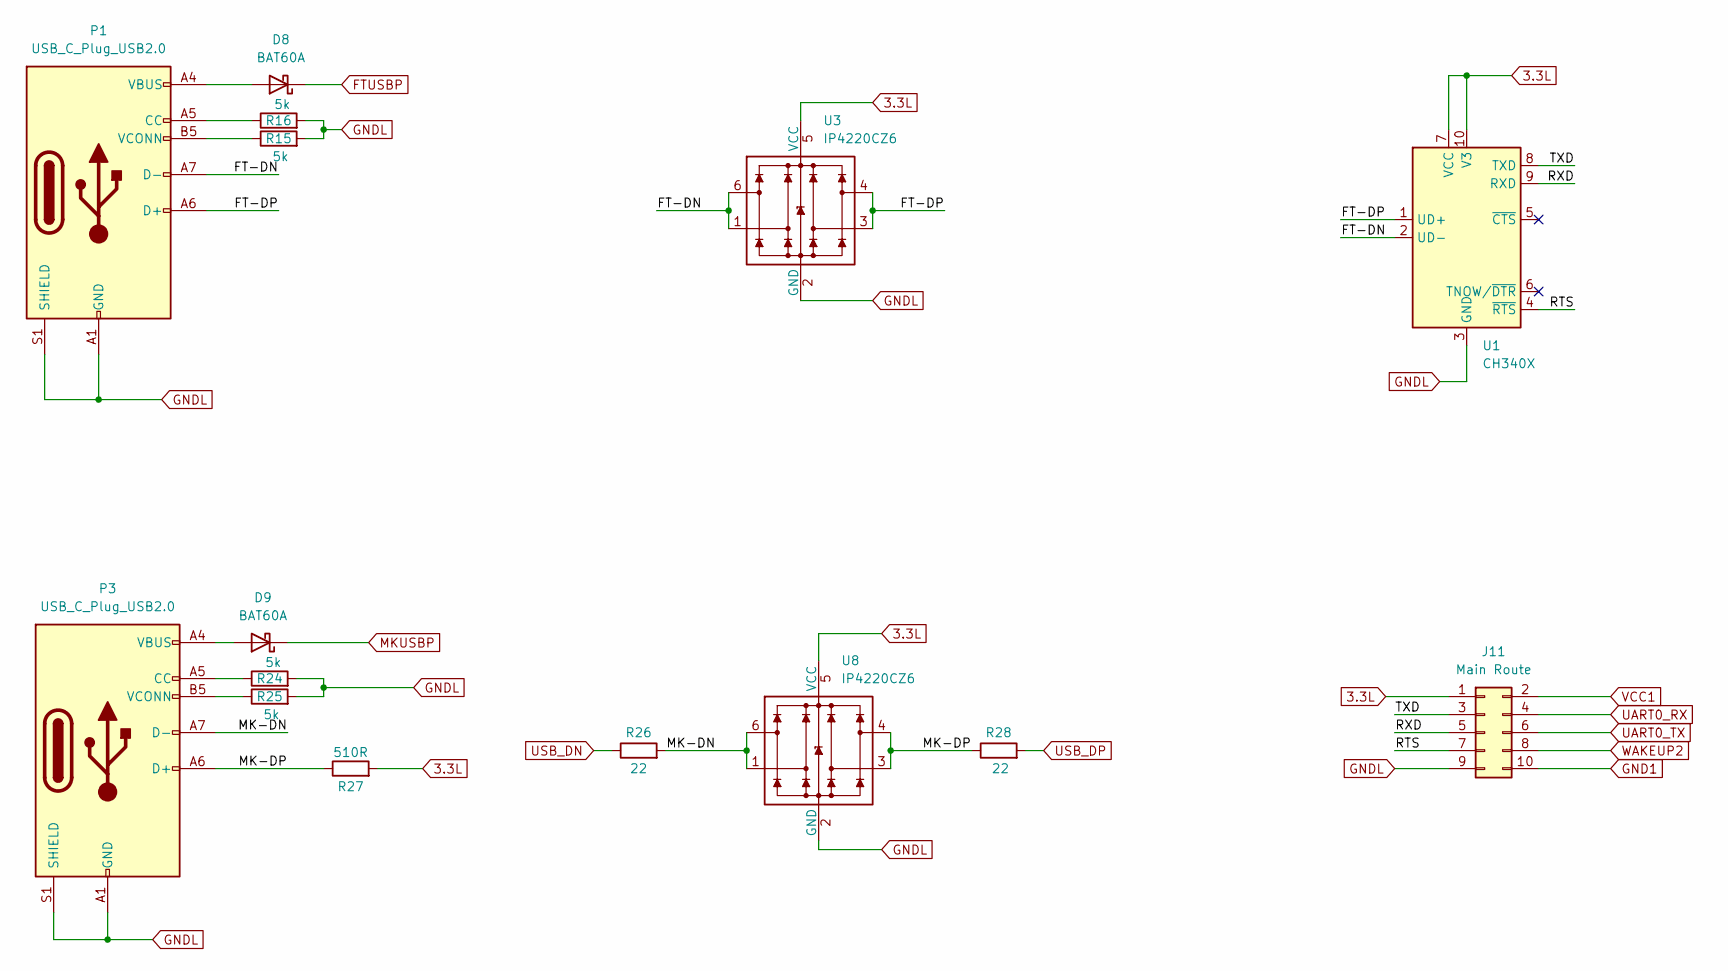
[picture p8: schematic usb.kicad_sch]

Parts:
D8, D9: BAT60A; D_SOD-323
J11: Main Route; PinHeader_2x05_P2.54mm_Vertical
P1, P3: USB_C_Plug_USB2.0; USB_C_Receptacle_HRO_TYPE-C-31-M-12
R15, R16, R24, R25: 5k; R_0805_2012Metric
R26, R28: 22; R_0805_2012Metric
R27: 510R; R_0805_2012Metric
U1: CH340X; MSOP-10_3x3mm_P0.5mm
U3, U8: IP4220CZ6; SC-74-6_1.55x2.9mm_P0.95mm

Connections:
3.3L: J11.1, R27.2, U1.7 (VCC), U1.10 (V3), U3.5 (VCC), U8.5 (VCC); also elsewhere on the board
/USB/FT-DN: P1.A7 (D-), U1.2 (UD-), U3.1, U3.6
/USB/FT-DP: P1.A6 (D+), U1.1 (UD+), U3.3, U3.4
/USB/MK-DN: P3.A7 (D-), R26.2, U8.1, U8.6
/USB/MK-DP: P3.A6 (D+), R27.1, R28.1, U8.3, U8.4
/USB/RTS: J11.7, U1.4 (~RTS)
/USB/RXD: J11.5, U1.9 (RXD)
/USB/TXD: J11.3, U1.8 (TXD)
FTUSBP: D8.1 (K); also elsewhere on the board
GND1: J11.10; also elsewhere on the board
GNDL: J11.9, P1.A1 (GND), P1.A12 (GND), P1.B1 (GND), P1.B12 (GND), P1.S1 (SHIELD), P3.A1 (GND), P3.A12 (GND), P3.B1 (GND), P3.B12 (GND), P3.S1 (SHIELD), R15.2, R16.2, R24.2, R25.2, U1.3 (GND), U3.2 (GND), U8.2 (GND); also elsewhere on the board
MKUSBP: D9.1 (K); also elsewhere on the board
unnamed: D8.2 (A), P1.A4 (VBUS), P1.A9 (VBUS), P1.B4 (VBUS), P1.B9 (VBUS)
unnamed: D9.2 (A), P3.A4 (VBUS), P3.A9 (VBUS), P3.B4 (VBUS), P3.B9 (VBUS)
unnamed: P1.A5 (CC), R16.1
unnamed: P1.B5 (VCONN), R15.1
unnamed: P3.A5 (CC), R24.1
unnamed: P3.B5 (VCONN), R25.1
PA0: J11.4; also elsewhere on the board
PA1: J11.6; also elsewhere on the board
USB_DN: R26.1; also elsewhere on the board
USB_DP: R28.2; also elsewhere on the board
VCC1: J11.2; also elsewhere on the board
WAKEUP2: J11.8; also elsewhere on the board

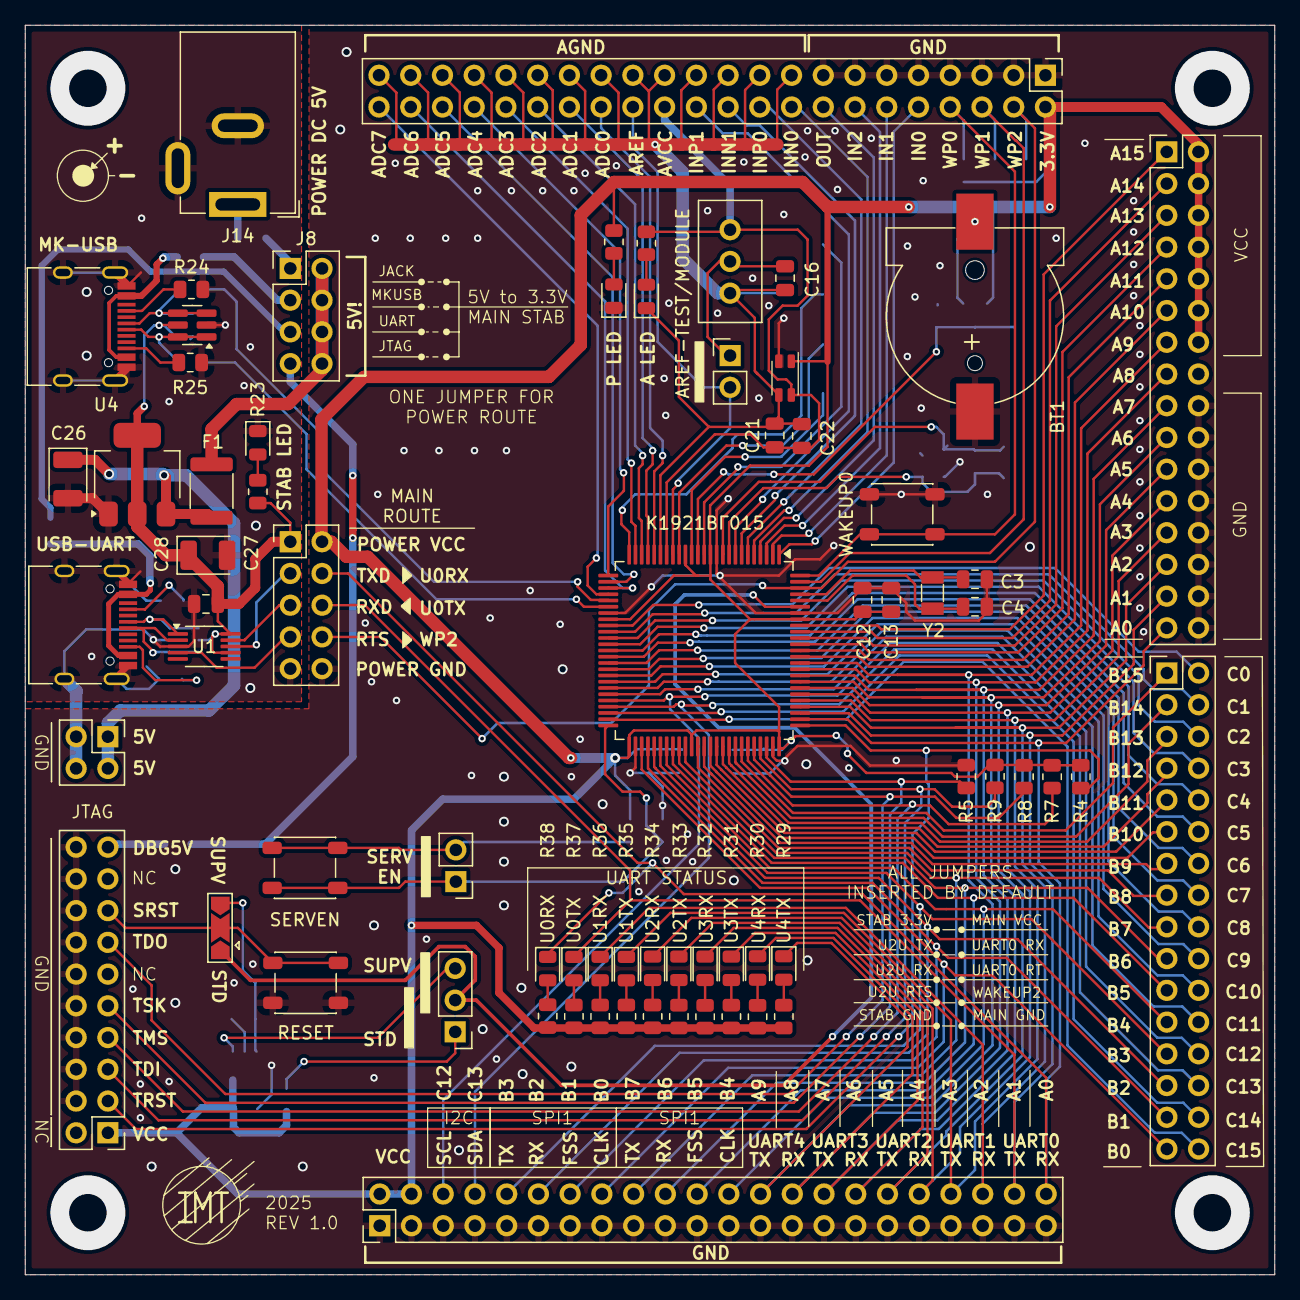
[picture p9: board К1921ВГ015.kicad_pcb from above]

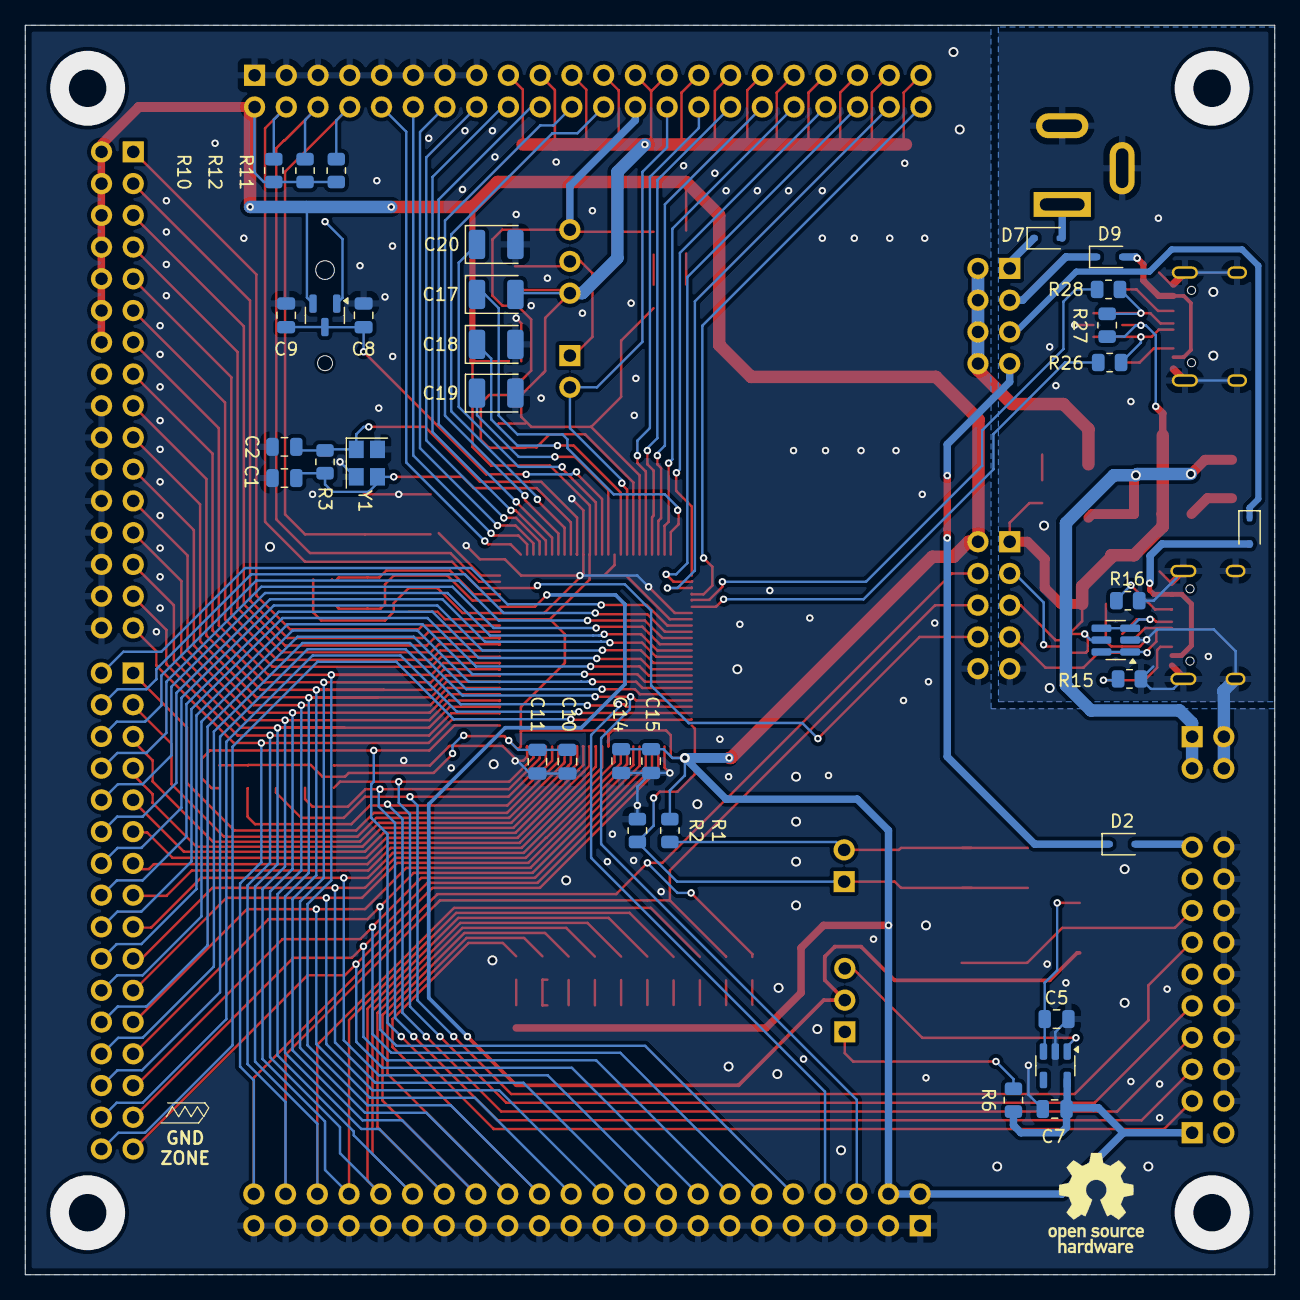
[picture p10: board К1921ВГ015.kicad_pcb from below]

Board: 2 copper layers, 100.0 x 100.0 mm, 104 parts (34 on the bottom side), 133 nets.

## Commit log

2025-05-16 Add AGND capacitors
    [main.kicad_sch, power.kicad_sch, К1921ВГ015.kicad_pcb]
2025-05-16 Update APower
    [power.kicad_sch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]
2025-05-18 3D-модели предохранителя и фильтра
2025-05-19 Обновление 3D моделей от cryptozoy
    [К1921ВГ015.kicad_pcb]
2025-05-19 3D модели разъёмов питания и USB
2025-05-19 Еще обновление 3D моделей от cryptozoy
    Обновление Barrel Jack + TypeC
    [К1921ВГ015.kicad_pcb]
2025-05-20 Питание 5V от JTAG, множественные исправления
    [extends.kicad_sch, main.kicad_sch, power.kicad_sch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]
2025-05-20 Update gerber & drl files
    [К1921ВГ015-B_Cu.gbr, К1921ВГ015-B_Mask.gbr, К1921ВГ015-B_Paste.gbr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]
2025-05-23 Обновление изображений
2025-05-23 Установочное место и 3D-модель держателя батареи
2025-05-23 Обновление платы
    [main.kicad_sch, К1921ВГ015.kicad_pcb]
